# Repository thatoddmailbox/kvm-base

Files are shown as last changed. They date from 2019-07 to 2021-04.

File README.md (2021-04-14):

# kvm-base


The main board for the [open-source HDMI KVM switch I built](https://github.com/thatoddmailbox/kvm#kvm). Contains HDMI and USB switch ICs, allowing you to share two monitors and four USB devices between three different computers.

This is a 1.6mm four layer PCB, designed for JLCPCB's [JLC7628](https://jlcpcb.com/quote/pcbOrderFaq/PCB%20Stackup) impedance-controlled stackup. It most likely will not work (or will be limited in terms of HDMI performance) on another stackup.

It connects via a PS/2 cable to [kvm-keypad](https://github.com/thatoddmailbox/kvm-keypad)&mdash;however, it does _not_ use the actual PS/2 protocol.

Two [TMDS361B](https://www.ti.com/lit/ds/symlink/tmds361b.pdf) chips are used as HDMI switches, and an [FSUSB74](https://www.onsemi.com/pub/Collateral/FSUSB74-D.pdf) is used as the USB switch.

## Assembly
The full Bill of Materials is linked at the end of the README, and you should get the PCB fabricated at JLCPCB with their impedance-controlled JLC7628 process.

A stencil is probably the easiest way to assemble the board, but it's definitely possible to do so without one, as long as you have a hot air rework station. The trickiest parts to solder are probably the FSUSB74 (QFN with 0.4 mm pitch but no thermal pad) and the TMDS361B (TQFP with 0.5 mm pitch).

The HDMI connectors are also somewhat tricky, given that they are on both sides of the board and also have a relatively fine pitch. However, it's doable with a soldering iron, flux, solder wick, and ideally some form of magnification&mdash;you just have to be careful to ensure the pins are aligned with the footprint on the board before soldering.

## Note on sink-side output stages
Interestingly, the TMDS361B's datasheet pretty clearly states that it's "not intended for source side applications such as external switch boxes", which I probably missed when designing this board.

The consequences of this seem to be that there's little/no ESD protection on the sink side (the monitor output ports), and that the chip has a fairly weak sink-side output stage. That means you probably can't use the output with super long or super cheap cables. The inputs, however, should be fine, since TI claims that the TMDS361B has a "robust TMDS receive stage" that even works with out-of-spec HDMI signals.

Anecdotally, the output does seem to work, but I haven't tested it in that many conditions. This has been tested with a 3 foot HDMI cable going to an Acer EB243YU monitor, using a resolution of 2560 x 1440 at 75 Hz, which is outside of the TMDS361B's spec!

Theoretically, you might be able to work around this by running the output signals to another board with a retimer or redriver, but that's probably somewhat excessive. A future revision should use a different chip and/or integrate a retimer/redriver to the output stage. Unfortunately, it might be somewhat tricky to find an easily accessible HDMI switch chip&mdash;most seem to want you to sign an NDA before getting any documentation.

## Useful links
* [Rev A schematic](./mfg/revA/kvm-base.pdf)
* [Rev A BOM](./mfg/revA/kvm-base.csv)

## Known issues
* TMDS361B's sink-side output stages, as mentioned above
* HDMI ports are too close together -- some cables might be too big to fit
* Some FSUSB74 ports seem to not be working -- this could be a soldering issue
	* Port 2 works perfectly
	* With ports 0 and 1, the computer detects a device but then complains the device is not responding
	* Suspect that probably one of the D+/D- lines is not well connected
* The HPD and DDC lines are switched along with the ports. This means that switching ports will cause the connected source to think the monitor went away, which might not be what you want
	* A future version will probably need to have some sort of EDID cloning/emulation, or have some way to keep the HPD line high after the monitor is connected?
	* There is a workaround: cover the HPD pin (pin 19) of your HDMI cable with tape to block the HPD signal.
		* This workaround means that some sources, like a laptop, might not autodetect your HDMI cable. You'll need to have some way to rescan. On Linux, you can try the command `xrandr --listmonitors`.
		* This might be solvable by cutting the cable open and soldering a 10k resistor between HPD and +5V? That's somewhat extra though
* The device can kinda sorta be powered by a sink&mdash;most likely the ESD diodes in the TMDS361B are backfeeding power on the +5V line.
* The keypad might have some trouble with noise when a PS/2 cable is connected, although it has been worked around in the firmware. A future revision might need a buffer or redriver or something similar? Plain I2C is probably not the best choice for communication between the base and keypad.

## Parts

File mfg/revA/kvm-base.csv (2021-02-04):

Reference | Value | Footprint | Datasheet
U3 | STM8S003F3P | Package_SO:TSSOP-20_4.4x6.5mm_P0.65mm | http://www.st.com/st-web-ui/static/active/en/resource/technical/document/datasheet/DM00024550.pdf
U2 | FSUSB74 | kvm-base:UMLP16 | https://www.onsemi.com/pub/Collateral/FSUSB74-D.pdf
J1 | USB_B_Mini | Connector_USB:USB_Mini-B_Lumberg_2486_01_Horizontal | ~
J2 | USB_B_Mini | Connector_USB:USB_Mini-B_Lumberg_2486_01_Horizontal | ~
J3 | USB_B_Mini | Connector_USB:USB_Mini-B_Lumberg_2486_01_Horizontal | ~
J4 | USB_B_Mini | Connector_USB:USB_Mini-B_Lumberg_2486_01_Horizontal | ~
U1 | AMS1117-3.3 | Package_TO_SOT_SMD:SOT-223-3_TabPin2 | http://www.advanced-monolithic.com/pdf/ds1117.pdf
C1 | 10uF | Capacitor_SMD:C_0603_1608Metric_Pad1.05x0.95mm_HandSolder | ~
C2 | 10uF | Capacitor_SMD:C_0603_1608Metric_Pad1.05x0.95mm_HandSolder | ~
C3 | 0.1uF | Capacitor_SMD:C_0603_1608Metric_Pad1.05x0.95mm_HandSolder | ~
C5 | 0.1uF | Capacitor_SMD:C_0603_1608Metric_Pad1.05x0.95mm_HandSolder | ~
C4 | 0.47uF | Capacitor_SMD:C_0603_1608Metric_Pad1.05x0.95mm_HandSolder | ~
J6 | Debug | Connector_PinSocket_2.54mm:PinSocket_2x04_P2.54mm_Vertical | ~
SW1 | Reset | Button_Switch_SMD:SW_Push_1P1T_NO_6x6mm_H9.5mm | ~
J5 | Keypad | kvm-base:PS2 | http://service.powerdynamics.com/ec/Catalog17/Section%2011.pdf
R7 | 10k | Resistor_SMD:R_0603_1608Metric_Pad1.05x0.95mm_HandSolder | ~
R5 | 10k | Resistor_SMD:R_0603_1608Metric_Pad1.05x0.95mm_HandSolder | ~
R8 | 10k | Resistor_SMD:R_0603_1608Metric_Pad1.05x0.95mm_HandSolder | ~
R6 | 10k | Resistor_SMD:R_0603_1608Metric_Pad1.05x0.95mm_HandSolder | ~
J7 | HDMI_A | kvm-base:HDMI-001 | https://en.wikipedia.org/wiki/HDMI
J10 | HDMI_A | kvm-base:HDMI-001 | https://en.wikipedia.org/wiki/HDMI
U4 | TMDS361B | Package_QFP:LQFP-64_10x10mm_P0.5mm | https://www.ti.com/lit/ds/symlink/tmds361b.pdf
J9 | HDMI_A | kvm-base:HDMI-001 | https://en.wikipedia.org/wiki/HDMI
J8 | HDMI_A | kvm-base:HDMI-001 | https://en.wikipedia.org/wiki/HDMI
C6 | 1uF | Capacitor_SMD:C_0603_1608Metric_Pad1.05x0.95mm_HandSolder | ~
C7 | 1uF | Capacitor_SMD:C_0603_1608Metric_Pad1.05x0.95mm_HandSolder | ~
C8 | 0.1uF | Capacitor_SMD:C_0603_1608Metric_Pad1.05x0.95mm_HandSolder | ~
C9 | 0.1uF | Capacitor_SMD:C_0603_1608Metric_Pad1.05x0.95mm_HandSolder | ~
C10 | 1uF | Capacitor_SMD:C_0603_1608Metric_Pad1.05x0.95mm_HandSolder | ~
C11 | 1uF | Capacitor_SMD:C_0603_1608Metric_Pad1.05x0.95mm_HandSolder | ~
C12 | 0.1uF | Capacitor_SMD:C_0603_1608Metric_Pad1.05x0.95mm_HandSolder | ~
C13 | 0.1uF | Capacitor_SMD:C_0603_1608Metric_Pad1.05x0.95mm_HandSolder | ~
R2 | 4.02k | Resistor_SMD:R_0603_1608Metric_Pad1.05x0.95mm_HandSolder | ~
R1 | 10k | Resistor_SMD:R_0603_1608Metric_Pad1.05x0.95mm_HandSolder | ~
R9 | 5.9k | Resistor_SMD:R_0603_1608Metric_Pad1.05x0.95mm_HandSolder | ~
R10 | 5.9k | Resistor_SMD:R_0603_1608Metric_Pad1.05x0.95mm_HandSolder | ~
J11 | HDMI_A | kvm-base:HDMI-001 | https://en.wikipedia.org/wiki/HDMI
U5 | TMDS361B | Package_QFP:LQFP-64_10x10mm_P0.5mm | https://www.ti.com/lit/ds/symlink/tmds361b.pdf
J13 | HDMI_A | kvm-base:HDMI-001 | https://en.wikipedia.org/wiki/HDMI
J12 | HDMI_A | kvm-base:HDMI-001 | https://en.wikipedia.org/wiki/HDMI
C14 | 1uF | Capacitor_SMD:C_0603_1608Metric_Pad1.05x0.95mm_HandSolder | ~
C15 | 1uF | Capacitor_SMD:C_0603_1608Metric_Pad1.05x0.95mm_HandSolder | ~
C16 | 0.1uF | Capacitor_SMD:C_0603_1608Metric_Pad1.05x0.95mm_HandSolder | ~
C17 | 0.1uF | Capacitor_SMD:C_0603_1608Metric_Pad1.05x0.95mm_HandSolder | ~
C18 | 1uF | Capacitor_SMD:C_0603_1608Metric_Pad1.05x0.95mm_HandSolder | ~
C19 | 1uF | Capacitor_SMD:C_0603_1608Metric_Pad1.05x0.95mm_HandSolder | ~
C20 | 0.1uF | Capacitor_SMD:C_0603_1608Metric_Pad1.05x0.95mm_HandSolder | ~
C21 | 0.1uF | Capacitor_SMD:C_0603_1608Metric_Pad1.05x0.95mm_HandSolder | ~
R4 | 4.02k | Resistor_SMD:R_0603_1608Metric_Pad1.05x0.95mm_HandSolder | ~
R3 | 10k | Resistor_SMD:R_0603_1608Metric_Pad1.05x0.95mm_HandSolder | ~
J14 | HDMI_A | kvm-base:HDMI-001 | https://en.wikipedia.org/wiki/HDMI
R11 | 5.9k | Resistor_SMD:R_0603_1608Metric_Pad1.05x0.95mm_HandSolder | ~
R12 | 5.9k | Resistor_SMD:R_0603_1608Metric_Pad1.05x0.95mm_HandSolder | ~
U6 | SL2.1A | Package_SO:SOIC-16_3.9x9.9mm_P1.27mm
C24 | 10uF | Capacitor_SMD:C_0603_1608Metric_Pad1.05x0.95mm_HandSolder | ~
J15 | USB_Dual_A | Connector_USB:USB_A_Wuerth_61400826021_Horizontal_Stacked | ~
J16 | USB_Dual_A | Connector_USB:USB_A_Wuerth_61400826021_Horizontal_Stacked | ~
C25 | 10uF | Capacitor_SMD:C_0603_1608Metric_Pad1.05x0.95mm_HandSolder | ~
Y1 | 12MHz | Crystal:Crystal_SMD_3225-4Pin_3.2x2.5mm_HandSoldering | ~
C23 | 12pF | Capacitor_SMD:C_0603_1608Metric_Pad1.05x0.95mm_HandSolder | ~
C22 | 12pF | Capacitor_SMD:C_0603_1608Metric_Pad1.05x0.95mm_HandSolder | ~
C29 | 10uF | Capacitor_SMD:C_0603_1608Metric_Pad1.05x0.95mm_HandSolder | ~
C26 | 10uF | Capacitor_SMD:C_0603_1608Metric_Pad1.05x0.95mm_HandSolder | ~
C28 | 10uF | Capacitor_SMD:C_0603_1608Metric_Pad1.05x0.95mm_HandSolder | ~
C27 | 10uF | Capacitor_SMD:C_0603_1608Metric_Pad1.05x0.95mm_HandSolder | ~

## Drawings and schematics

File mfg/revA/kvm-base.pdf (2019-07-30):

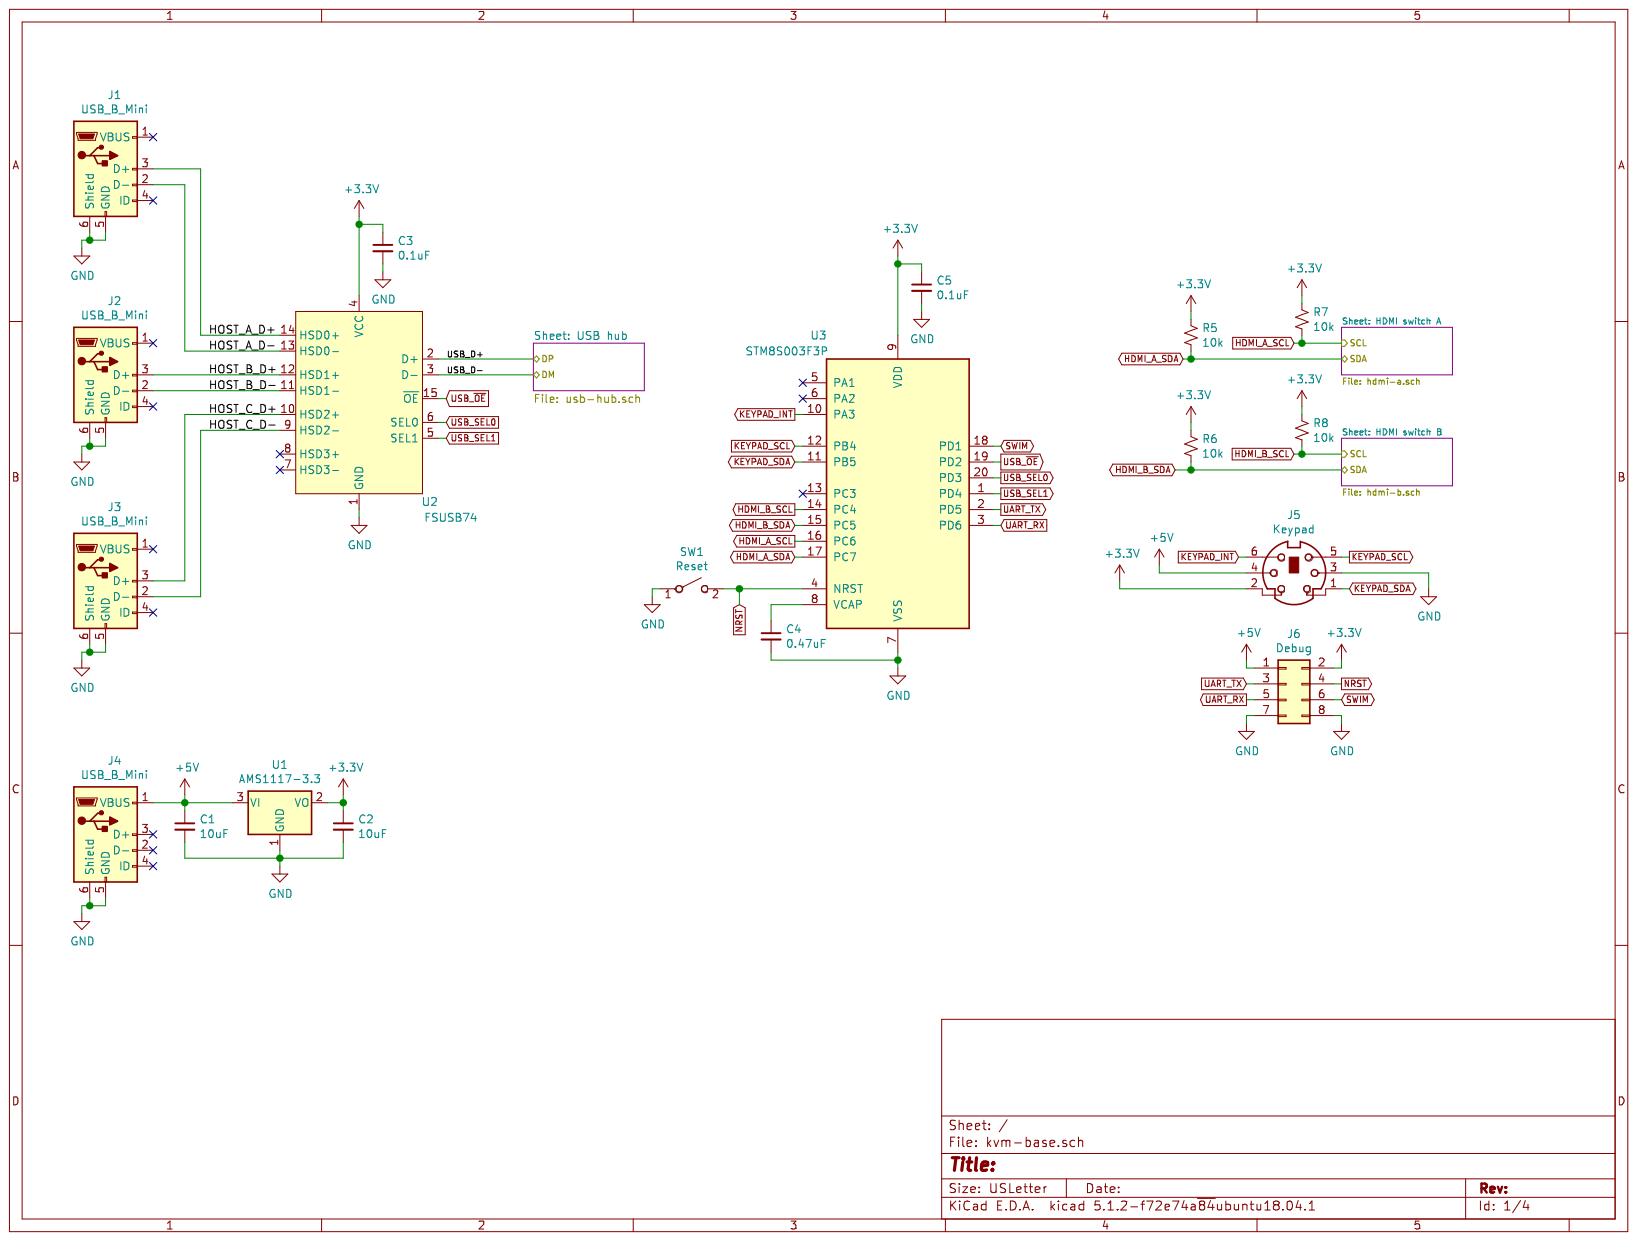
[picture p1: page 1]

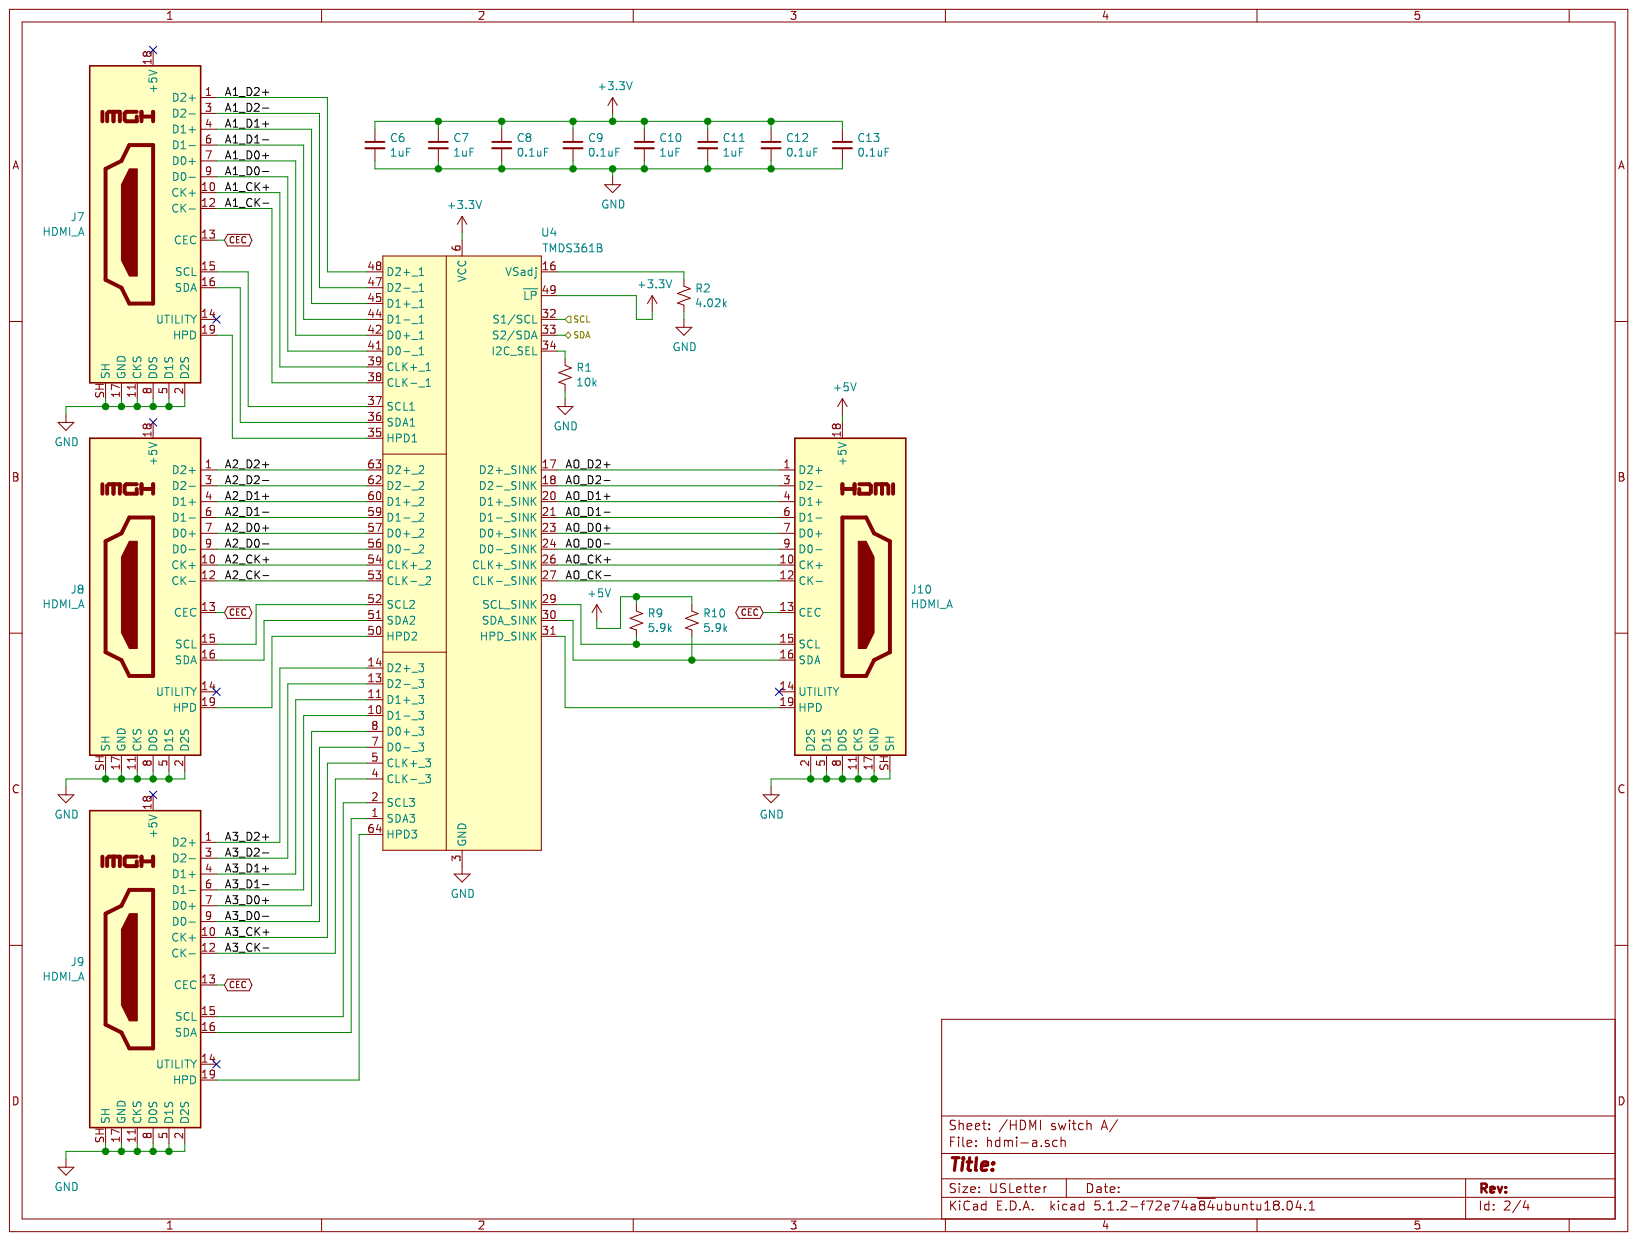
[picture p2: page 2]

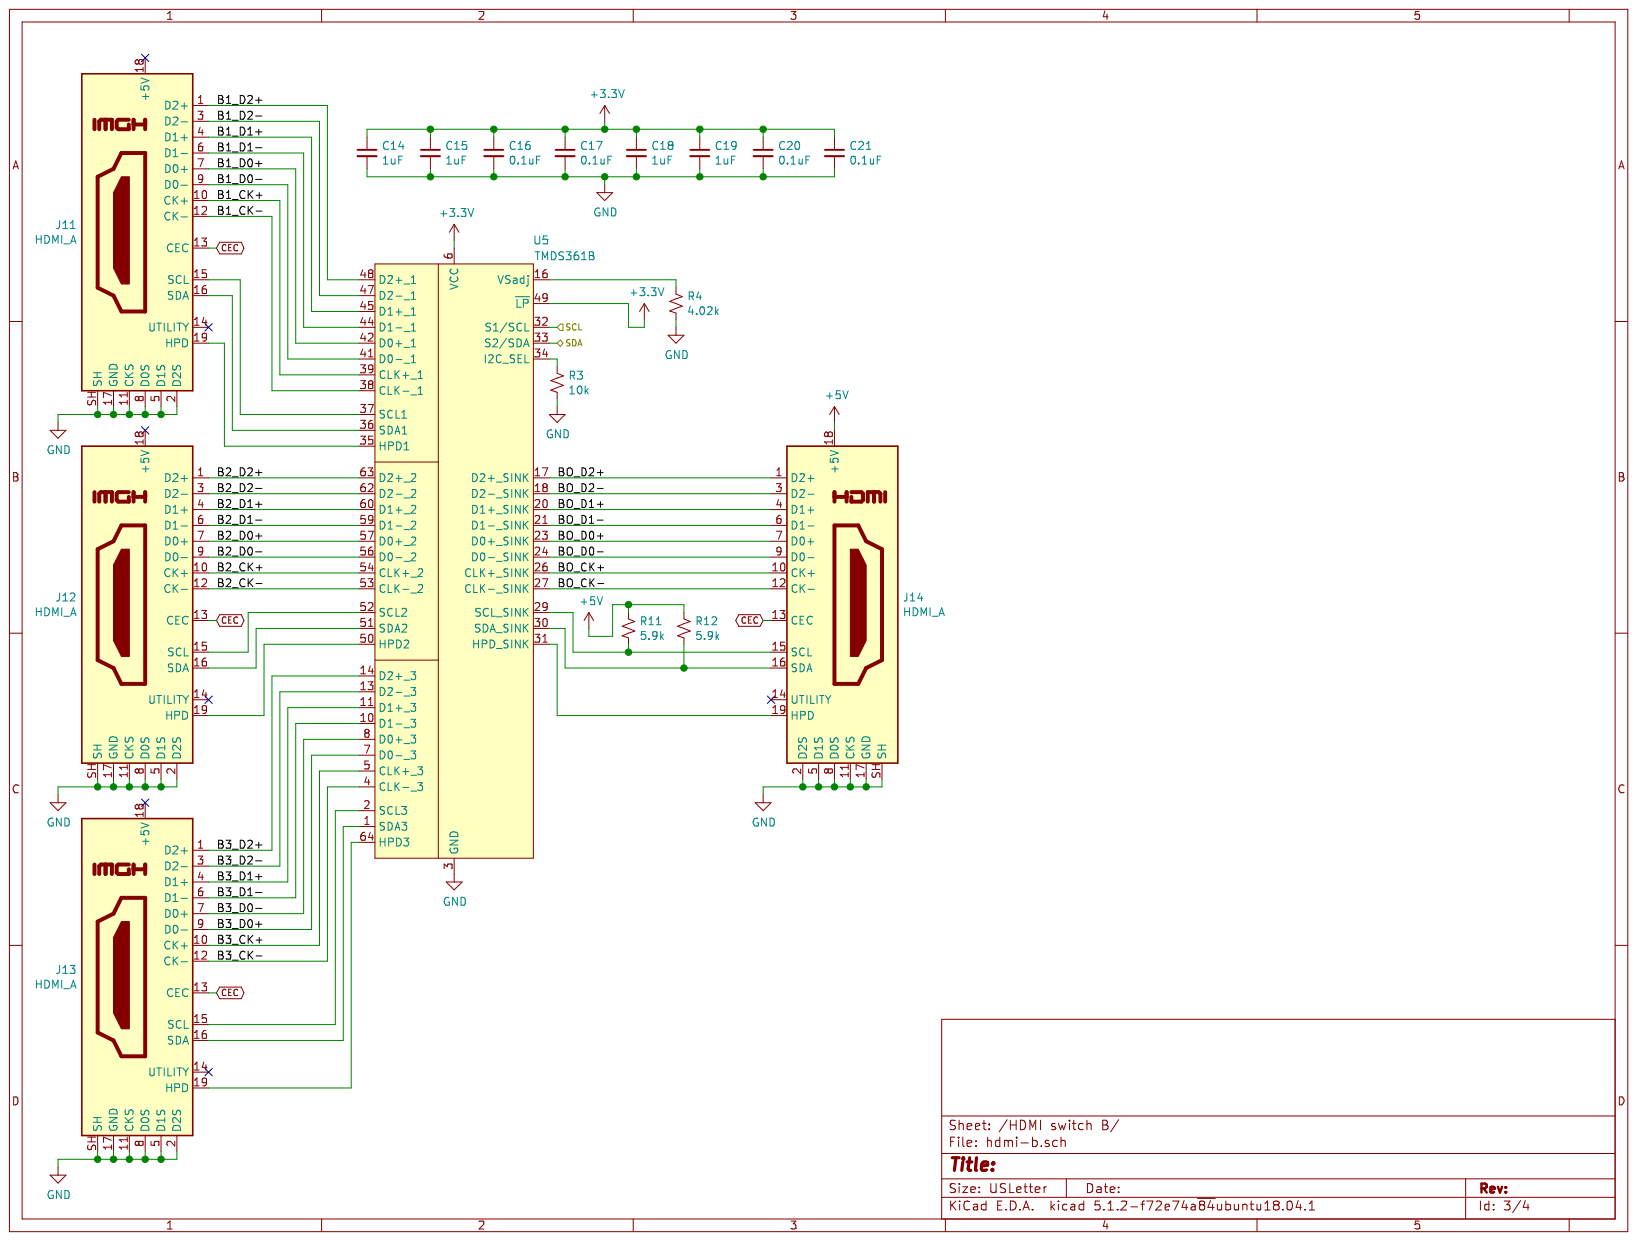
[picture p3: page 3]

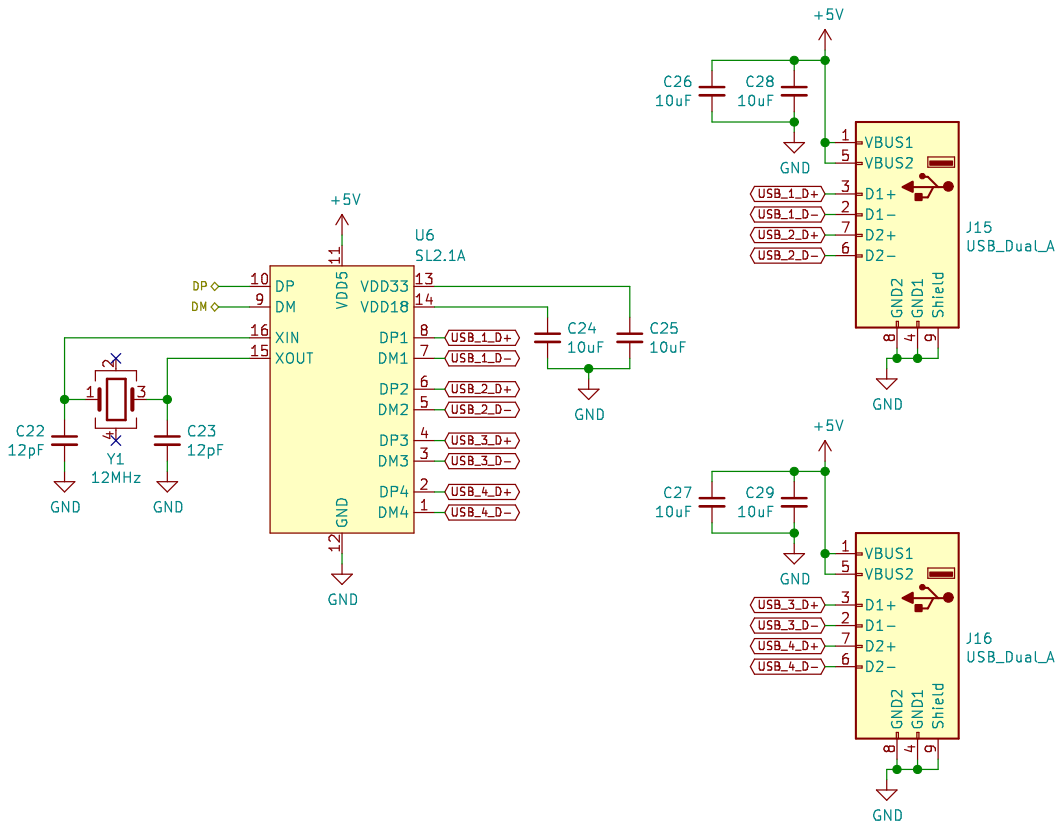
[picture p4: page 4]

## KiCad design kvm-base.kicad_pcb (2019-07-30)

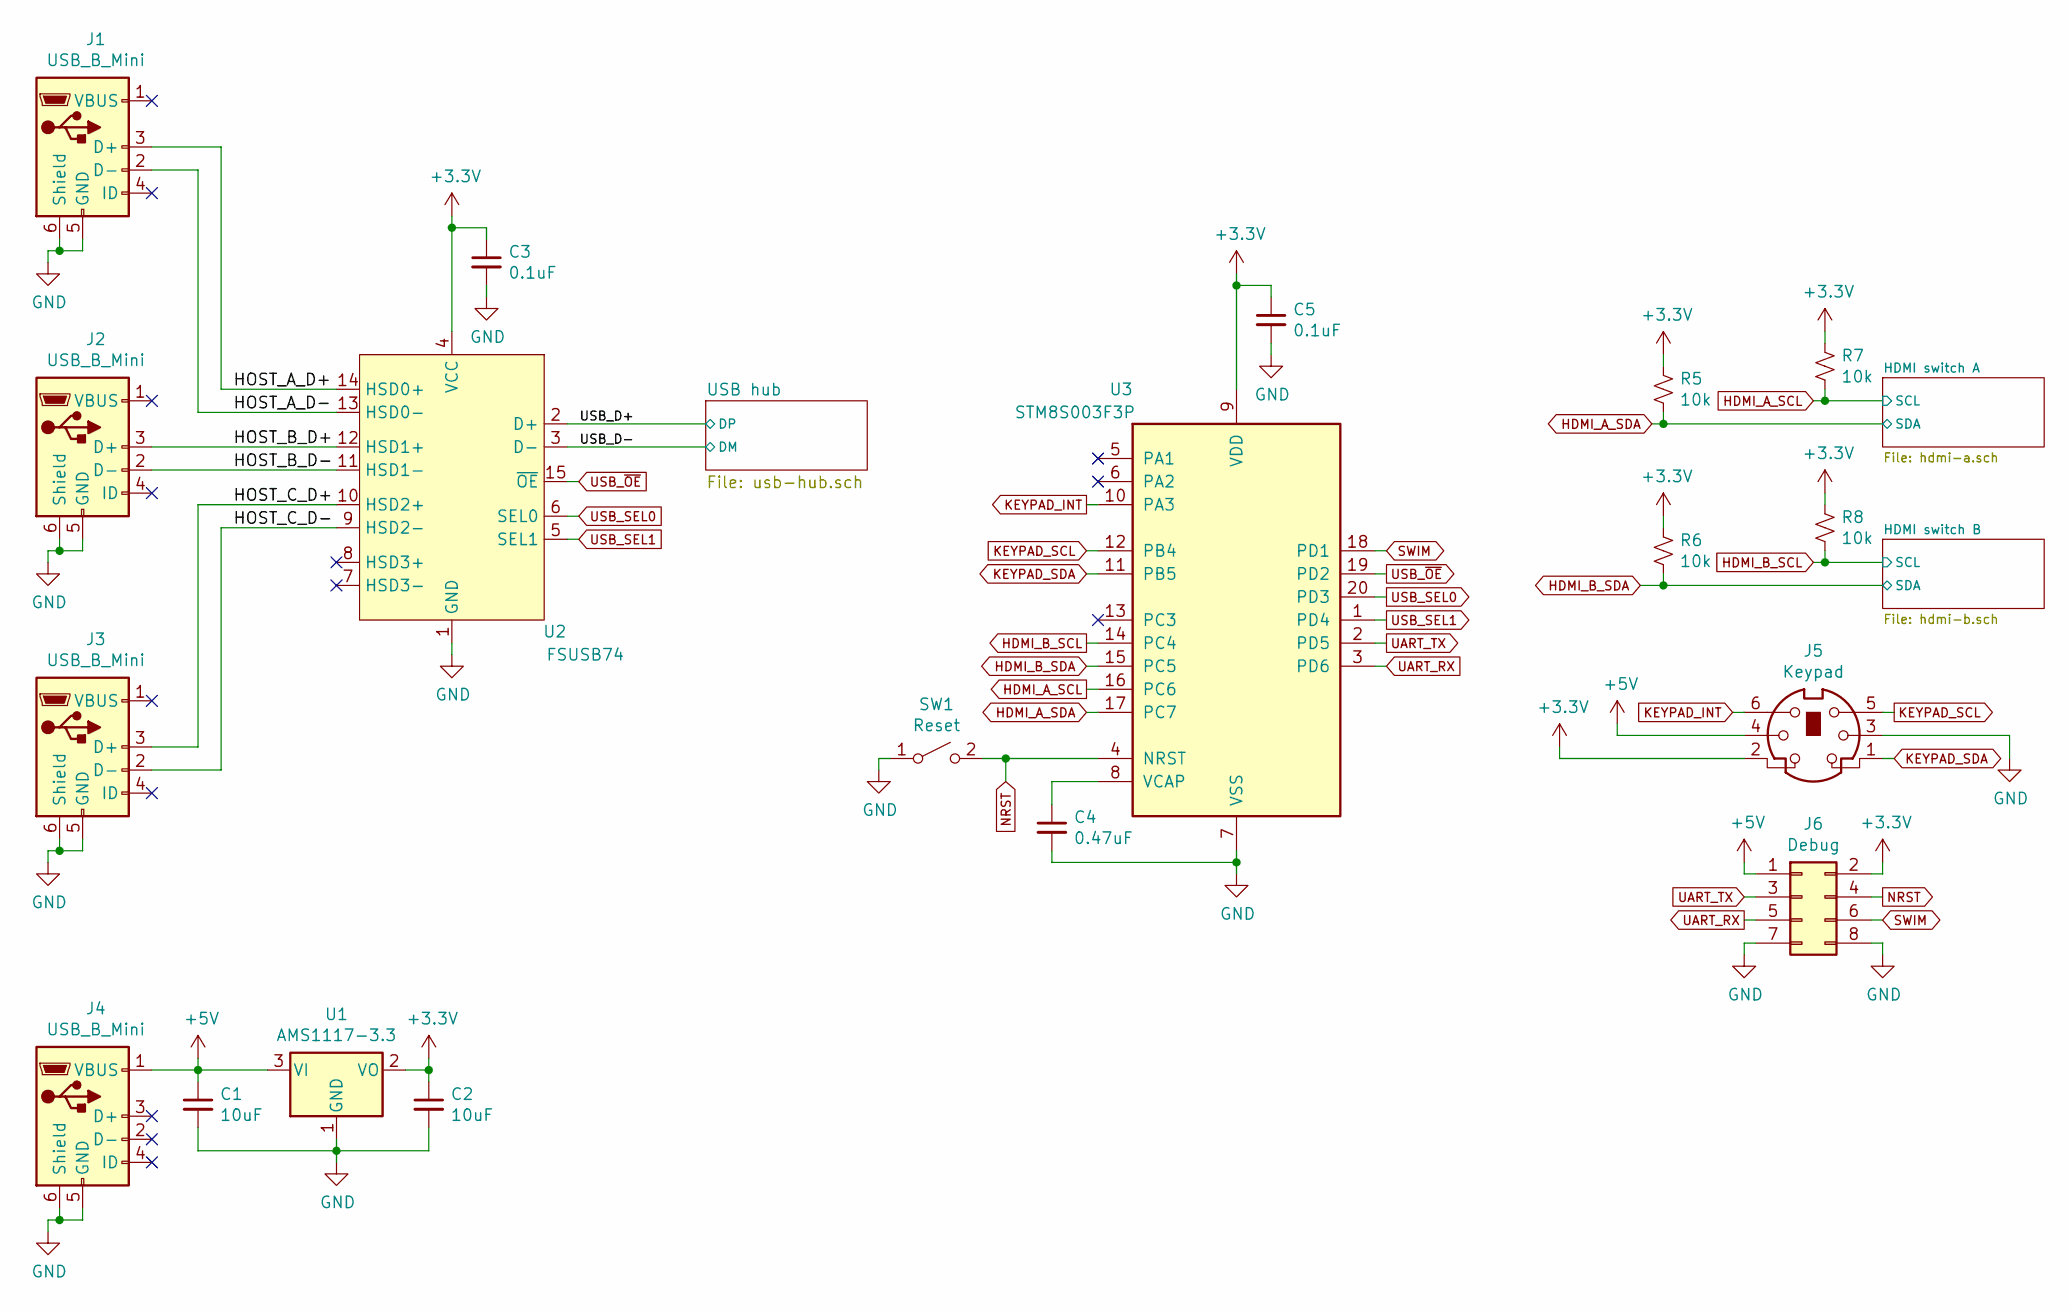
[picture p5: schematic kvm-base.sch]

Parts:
C1, C2: 10uF; C_0603_1608Metric_Pad1.05x0.95mm_HandSolder
C3, C5: 0.1uF; C_0603_1608Metric_Pad1.05x0.95mm_HandSolder
C4: 0.47uF; C_0603_1608Metric_Pad1.05x0.95mm_HandSolder
J1, J2, J3, J4: USB_B_Mini; USB_Mini-B_Lumberg_2486_01_Horizontal
J5: Keypad; PS2
J6: Debug; PinSocket_2x04_P2.54mm_Vertical
R5, R6, R7, R8: 10k; R_0603_1608Metric_Pad1.05x0.95mm_HandSolder
SW1: Reset; SW_Push_1P1T_NO_6x6mm_H9.5mm
U1: AMS1117-3.3; SOT-223-3_TabPin2
U2: FSUSB74; UMLP16
U3: STM8S003F3P; TSSOP-20_4.4x6.5mm_P0.65mm

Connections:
+3V3: C2.1, C3.1, C5.1, J5.2, J6.2, R5.1, R6.1, R7.1, R8.1, U1.2 (VO), U2.4 (VCC), U3.9 (VDD); also elsewhere on the board
+5V: C1.1, J4.1 (VBUS), J5.4, J6.1, U1.3 (VI); also elsewhere on the board
/HOST_A_D+: J1.3 (D+), U2.14 (HSD0+)
/HOST_A_D-: J1.2 (D-), U2.13 (HSD0-)
/HOST_B_D+: J2.3 (D+), U2.12 (HSD1+)
/HOST_B_D-: J2.2 (D-), U2.11 (HSD1-)
/HOST_C_D+: J3.3 (D+), U2.10 (HSD2+)
/HOST_C_D-: J3.2 (D-), U2.9 (HSD2-)
/USB_D+: U2.2 (D+); also elsewhere on the board
/USB_D-: U2.3 (D-); also elsewhere on the board
GND: C1.2, C2.2, C3.2, C4.2, C5.2, J1.5 (GND), J1.6 (Shield), J2.5 (GND), J2.6 (Shield), J3.5 (GND), J3.6 (Shield), J4.5 (GND), J4.6 (Shield), J5.3, J6.7, J6.8, SW1.1 (A), U1.1 (GND), U2.1 (GND), U3.7 (VSS); also elsewhere on the board
HDMI_A_SCL: R7.2, U3.16 (PC6); also elsewhere on the board
HDMI_A_SDA: R5.2, U3.17 (PC7); also elsewhere on the board
HDMI_B_SCL: R8.2, U3.14 (PC4); also elsewhere on the board
HDMI_B_SDA: R6.2, U3.15 (PC5); also elsewhere on the board
KEYPAD_INT: J5.6, U3.10 (PA3)
KEYPAD_SCL: J5.5, U3.12 (PB4)
KEYPAD_SDA: J5.1, U3.11 (PB5)
NRST: J6.4, SW1.2 (B), U3.4 (NRST)
unnamed: C4.1, U3.8 (VCAP)
SWIM: J6.6, U3.18 (PD1)
UART_RX: J6.5, U3.3 (PD6)
UART_TX: J6.3, U3.2 (PD5)
USB_SEL0: U2.6 (SEL0), U3.20 (PD3)
USB_SEL1: U2.5 (SEL1), U3.1 (PD4)
USB_~OE: U2.15 (~OE), U3.19 (PD2)

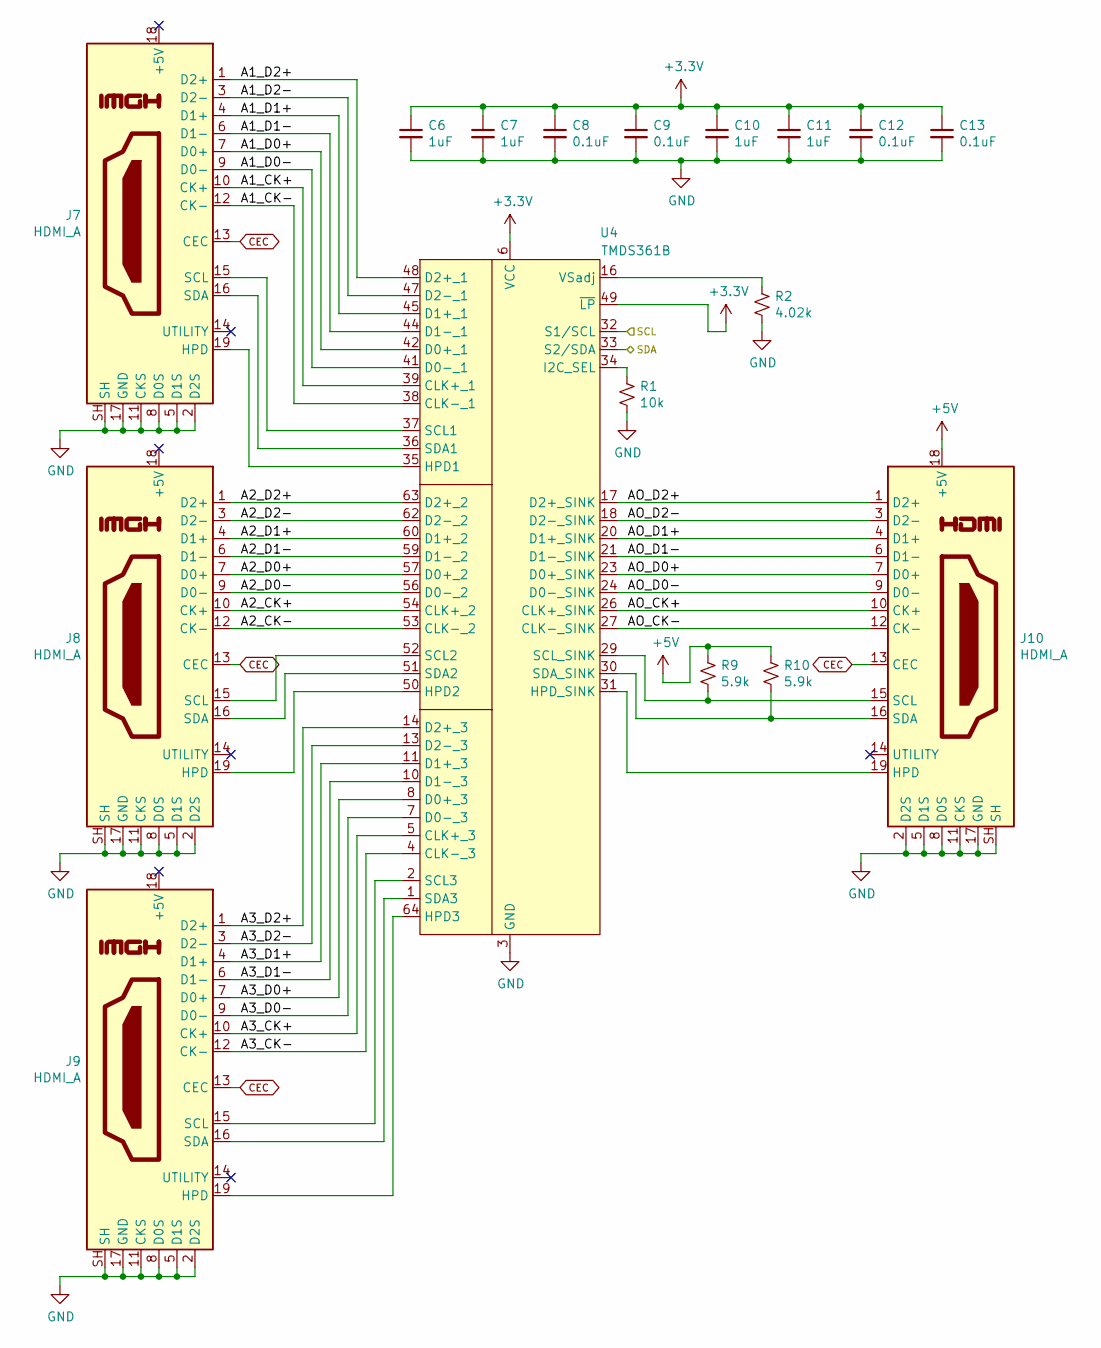
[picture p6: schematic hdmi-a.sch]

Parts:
C6, C7, C10, C11: 1uF; C_0603_1608Metric_Pad1.05x0.95mm_HandSolder
C8, C9, C12, C13: 0.1uF; C_0603_1608Metric_Pad1.05x0.95mm_HandSolder
J7, J8, J9, J10: HDMI_A; HDMI-001
R1: 10k; R_0603_1608Metric_Pad1.05x0.95mm_HandSolder
R2: 4.02k; R_0603_1608Metric_Pad1.05x0.95mm_HandSolder
R9, R10: 5.9k; R_0603_1608Metric_Pad1.05x0.95mm_HandSolder
U4: TMDS361B; LQFP-64_10x10mm_P0.5mm

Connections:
+3V3: C6.1, C7.1, C8.1, C9.1, C10.1, C11.1, C12.1, C13.1, U4.6 (VCC), U4.12 (VCC), U4.19 (VCC), U4.25 (VCC), U4.40 (VCC), U4.46 (VCC), U4.49 (~LP), U4.55 (VCC), U4.61 (VCC); also elsewhere on the board
+5V: J10.18 (+5V), R9.1, R10.1; also elsewhere on the board
/HDMI switch A/A1_CK+: J7.10 (CK+), U4.39 (CLK+_1)
/HDMI switch A/A1_CK-: J7.12 (CK-), U4.38 (CLK-_1)
/HDMI switch A/A1_D0+: J7.7 (D0+), U4.42 (D0+_1)
/HDMI switch A/A1_D0-: J7.9 (D0-), U4.41 (D0-_1)
/HDMI switch A/A1_D1+: J7.4 (D1+), U4.45 (D1+_1)
/HDMI switch A/A1_D1-: J7.6 (D1-), U4.44 (D1-_1)
/HDMI switch A/A1_D2+: J7.1 (D2+), U4.48 (D2+_1)
/HDMI switch A/A1_D2-: J7.3 (D2-), U4.47 (D2-_1)
/HDMI switch A/A2_CK+: J8.10 (CK+), U4.54 (CLK+_2)
/HDMI switch A/A2_CK-: J8.12 (CK-), U4.53 (CLK-_2)
/HDMI switch A/A2_D0+: J8.7 (D0+), U4.57 (D0+_2)
/HDMI switch A/A2_D0-: J8.9 (D0-), U4.56 (D0-_2)
/HDMI switch A/A2_D1+: J8.4 (D1+), U4.60 (D1+_2)
/HDMI switch A/A2_D1-: J8.6 (D1-), U4.59 (D1-_2)
/HDMI switch A/A2_D2+: J8.1 (D2+), U4.63 (D2+_2)
/HDMI switch A/A2_D2-: J8.3 (D2-), U4.62 (D2-_2)
/HDMI switch A/A3_CK+: J9.10 (CK+), U4.5 (CLK+_3)
/HDMI switch A/A3_CK-: J9.12 (CK-), U4.4 (CLK-_3)
/HDMI switch A/A3_D0+: J9.7 (D0+), U4.8 (D0+_3)
/HDMI switch A/A3_D0-: J9.9 (D0-), U4.7 (D0-_3)
/HDMI switch A/A3_D1+: J9.4 (D1+), U4.11 (D1+_3)
/HDMI switch A/A3_D1-: J9.6 (D1-), U4.10 (D1-_3)
/HDMI switch A/A3_D2+: J9.1 (D2+), U4.14 (D2+_3)
/HDMI switch A/A3_D2-: J9.3 (D2-), U4.13 (D2-_3)
/HDMI switch A/AO_CK+: J10.10 (CK+), U4.26 (CLK+_SINK)
/HDMI switch A/AO_CK-: J10.12 (CK-), U4.27 (CLK-_SINK)
/HDMI switch A/AO_D0+: J10.7 (D0+), U4.23 (D0+_SINK)
/HDMI switch A/AO_D0-: J10.9 (D0-), U4.24 (D0-_SINK)
/HDMI switch A/AO_D1+: J10.4 (D1+), U4.20 (D1+_SINK)
/HDMI switch A/AO_D1-: J10.6 (D1-), U4.21 (D1-_SINK)
/HDMI switch A/AO_D2+: J10.1 (D2+), U4.17 (D2+_SINK)
/HDMI switch A/AO_D2-: J10.3 (D2-), U4.18 (D2-_SINK)
CEC: J7.13 (CEC), J8.13 (CEC), J9.13 (CEC), J10.13 (CEC); also elsewhere on the board
GND: C6.2, C7.2, C8.2, C9.2, C10.2, C11.2, C12.2, C13.2, J7.2 (D2S), J7.5 (D1S), J7.8 (D0S), J7.11 (CKS), J7.17 (GND), J7.SH, J8.2 (D2S), J8.5 (D1S), J8.8 (D0S), J8.11 (CKS), J8.17 (GND), J8.SH, J9.2 (D2S), J9.5 (D1S), J9.8 (D0S), J9.11 (CKS), J9.17 (GND), J9.SH, J10.2 (D2S), J10.5 (D1S), J10.8 (D0S), J10.11 (CKS), J10.17 (GND), J10.SH, R1.2, R2.2, U4.3 (GND), U4.9 (GND), U4.15 (GND), U4.22 (GND), U4.28 (GND), U4.43 (GND), U4.58 (GND); also elsewhere on the board
HDMI_A_SCL: U4.32 (S1/SCL); also elsewhere on the board
HDMI_A_SDA: U4.33 (S2/SDA); also elsewhere on the board
unnamed: J7.15 (SCL), U4.37 (SCL1)
unnamed: J7.16 (SDA), U4.36 (SDA1)
unnamed: J7.19 (HPD), U4.35 (HPD1)
unnamed: J8.15 (SCL), U4.52 (SCL2)
unnamed: J8.16 (SDA), U4.51 (SDA2)
unnamed: J8.19 (HPD), U4.50 (HPD2)
unnamed: J9.15 (SCL), U4.2 (SCL3)
unnamed: J9.16 (SDA), U4.1 (SDA3)
unnamed: J9.19 (HPD), U4.64 (HPD3)
unnamed: J10.15 (SCL), R9.2, U4.29 (SCL_SINK)
unnamed: J10.16 (SDA), R10.2, U4.30 (SDA_SINK)
unnamed: J10.19 (HPD), U4.31 (HPD_SINK)
unnamed: R1.1, U4.34 (I2C_SEL)
unnamed: R2.1, U4.16 (VSadj)

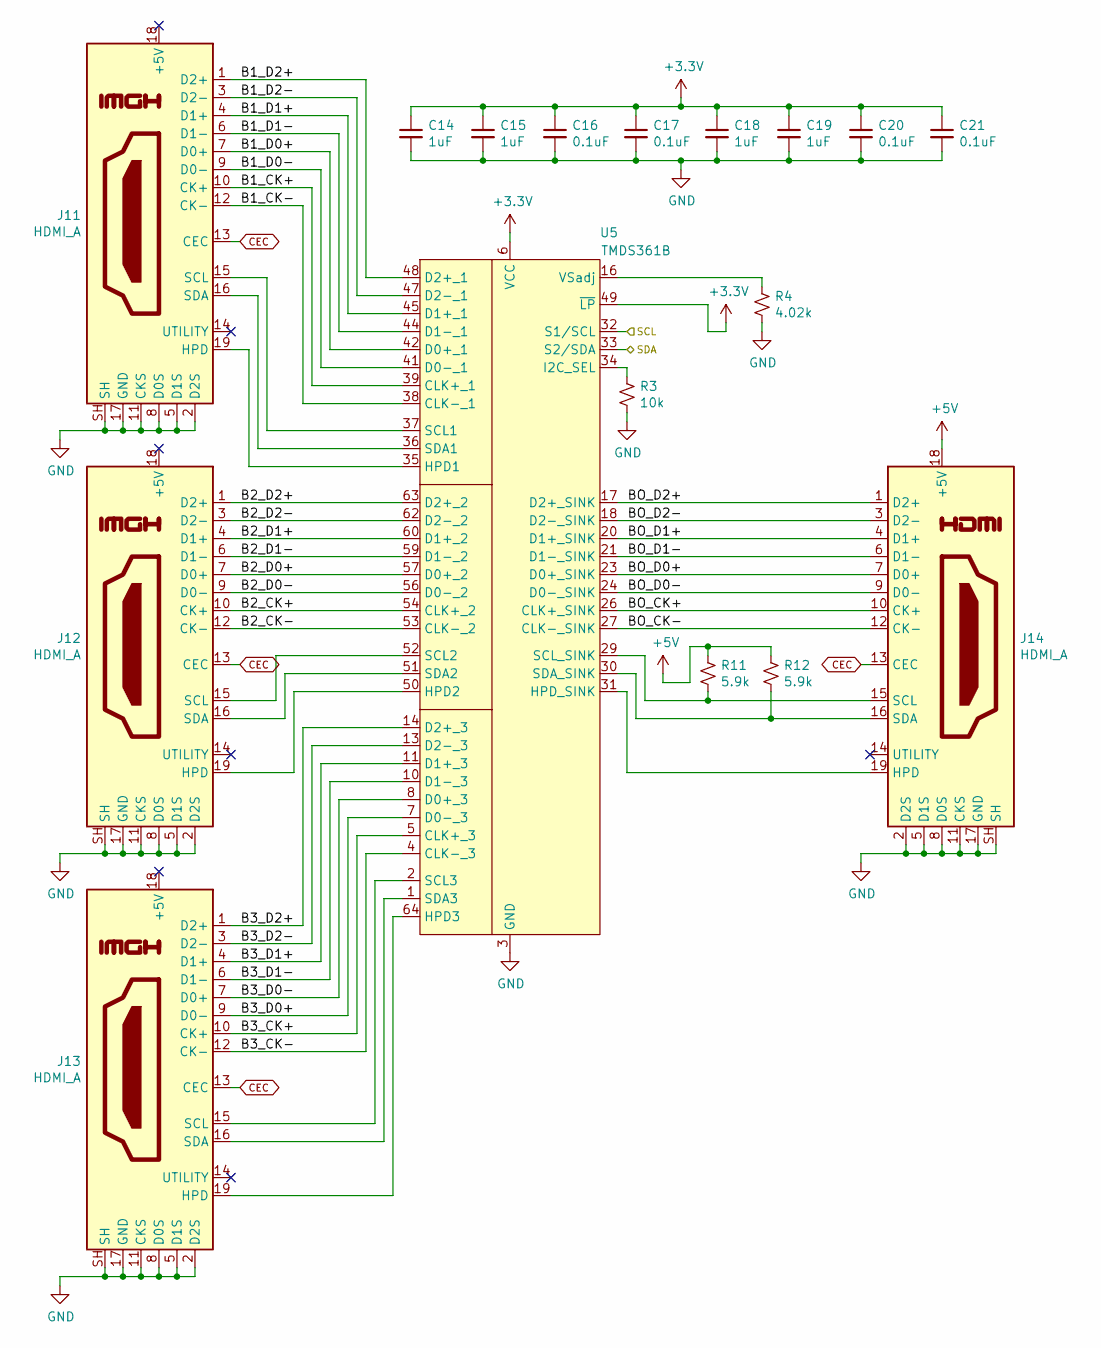
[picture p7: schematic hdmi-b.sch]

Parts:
C14, C15, C18, C19: 1uF; C_0603_1608Metric_Pad1.05x0.95mm_HandSolder
C16, C17, C20, C21: 0.1uF; C_0603_1608Metric_Pad1.05x0.95mm_HandSolder
J11, J12, J13, J14: HDMI_A; HDMI-001
R3: 10k; R_0603_1608Metric_Pad1.05x0.95mm_HandSolder
R4: 4.02k; R_0603_1608Metric_Pad1.05x0.95mm_HandSolder
R11, R12: 5.9k; R_0603_1608Metric_Pad1.05x0.95mm_HandSolder
U5: TMDS361B; LQFP-64_10x10mm_P0.5mm

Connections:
+3V3: C14.1, C15.1, C16.1, C17.1, C18.1, C19.1, C20.1, C21.1, U5.6 (VCC), U5.12 (VCC), U5.19 (VCC), U5.25 (VCC), U5.40 (VCC), U5.46 (VCC), U5.49 (~LP), U5.55 (VCC), U5.61 (VCC); also elsewhere on the board
+5V: J14.18 (+5V), R11.1, R12.1; also elsewhere on the board
/HDMI switch B/B1_CK+: J11.10 (CK+), U5.39 (CLK+_1)
/HDMI switch B/B1_CK-: J11.12 (CK-), U5.38 (CLK-_1)
/HDMI switch B/B1_D0+: J11.7 (D0+), U5.42 (D0+_1)
/HDMI switch B/B1_D0-: J11.9 (D0-), U5.41 (D0-_1)
/HDMI switch B/B1_D1+: J11.4 (D1+), U5.45 (D1+_1)
/HDMI switch B/B1_D1-: J11.6 (D1-), U5.44 (D1-_1)
/HDMI switch B/B1_D2+: J11.1 (D2+), U5.48 (D2+_1)
/HDMI switch B/B1_D2-: J11.3 (D2-), U5.47 (D2-_1)
/HDMI switch B/B2_CK+: J12.10 (CK+), U5.54 (CLK+_2)
/HDMI switch B/B2_CK-: J12.12 (CK-), U5.53 (CLK-_2)
/HDMI switch B/B2_D0+: J12.7 (D0+), U5.57 (D0+_2)
/HDMI switch B/B2_D0-: J12.9 (D0-), U5.56 (D0-_2)
/HDMI switch B/B2_D1+: J12.4 (D1+), U5.60 (D1+_2)
/HDMI switch B/B2_D1-: J12.6 (D1-), U5.59 (D1-_2)
/HDMI switch B/B2_D2+: J12.1 (D2+), U5.63 (D2+_2)
/HDMI switch B/B2_D2-: J12.3 (D2-), U5.62 (D2-_2)
/HDMI switch B/B3_CK+: J13.10 (CK+), U5.5 (CLK+_3)
/HDMI switch B/B3_CK-: J13.12 (CK-), U5.4 (CLK-_3)
/HDMI switch B/B3_D0+: J13.9 (D0-), U5.7 (D0-_3)
/HDMI switch B/B3_D0-: J13.7 (D0+), U5.8 (D0+_3)
/HDMI switch B/B3_D1+: J13.4 (D1+), U5.11 (D1+_3)
/HDMI switch B/B3_D1-: J13.6 (D1-), U5.10 (D1-_3)
/HDMI switch B/B3_D2+: J13.1 (D2+), U5.14 (D2+_3)
/HDMI switch B/B3_D2-: J13.3 (D2-), U5.13 (D2-_3)
/HDMI switch B/BO_CK+: J14.10 (CK+), U5.26 (CLK+_SINK)
/HDMI switch B/BO_CK-: J14.12 (CK-), U5.27 (CLK-_SINK)
/HDMI switch B/BO_D0+: J14.7 (D0+), U5.23 (D0+_SINK)
/HDMI switch B/BO_D0-: J14.9 (D0-), U5.24 (D0-_SINK)
/HDMI switch B/BO_D1+: J14.4 (D1+), U5.20 (D1+_SINK)
/HDMI switch B/BO_D1-: J14.6 (D1-), U5.21 (D1-_SINK)
/HDMI switch B/BO_D2+: J14.1 (D2+), U5.17 (D2+_SINK)
/HDMI switch B/BO_D2-: J14.3 (D2-), U5.18 (D2-_SINK)
CEC: J11.13 (CEC), J12.13 (CEC), J13.13 (CEC), J14.13 (CEC); also elsewhere on the board
GND: C14.2, C15.2, C16.2, C17.2, C18.2, C19.2, C20.2, C21.2, J11.2 (D2S), J11.5 (D1S), J11.8 (D0S), J11.11 (CKS), J11.17 (GND), J11.SH, J12.2 (D2S), J12.5 (D1S), J12.8 (D0S), J12.11 (CKS), J12.17 (GND), J12.SH, J13.2 (D2S), J13.5 (D1S), J13.8 (D0S), J13.11 (CKS), J13.17 (GND), J13.SH, J14.2 (D2S), J14.5 (D1S), J14.8 (D0S), J14.11 (CKS), J14.17 (GND), J14.SH, R3.2, R4.2, U5.3 (GND), U5.9 (GND), U5.15 (GND), U5.22 (GND), U5.28 (GND), U5.43 (GND), U5.58 (GND); also elsewhere on the board
HDMI_B_SCL: U5.32 (S1/SCL); also elsewhere on the board
HDMI_B_SDA: U5.33 (S2/SDA); also elsewhere on the board
unnamed: J11.15 (SCL), U5.37 (SCL1)
unnamed: J11.16 (SDA), U5.36 (SDA1)
unnamed: J11.19 (HPD), U5.35 (HPD1)
unnamed: J12.15 (SCL), U5.52 (SCL2)
unnamed: J12.16 (SDA), U5.51 (SDA2)
unnamed: J12.19 (HPD), U5.50 (HPD2)
unnamed: J13.15 (SCL), U5.2 (SCL3)
unnamed: J13.16 (SDA), U5.1 (SDA3)
unnamed: J13.19 (HPD), U5.64 (HPD3)
unnamed: J14.15 (SCL), R11.2, U5.29 (SCL_SINK)
unnamed: J14.16 (SDA), R12.2, U5.30 (SDA_SINK)
unnamed: J14.19 (HPD), U5.31 (HPD_SINK)
unnamed: R3.1, U5.34 (I2C_SEL)
unnamed: R4.1, U5.16 (VSadj)

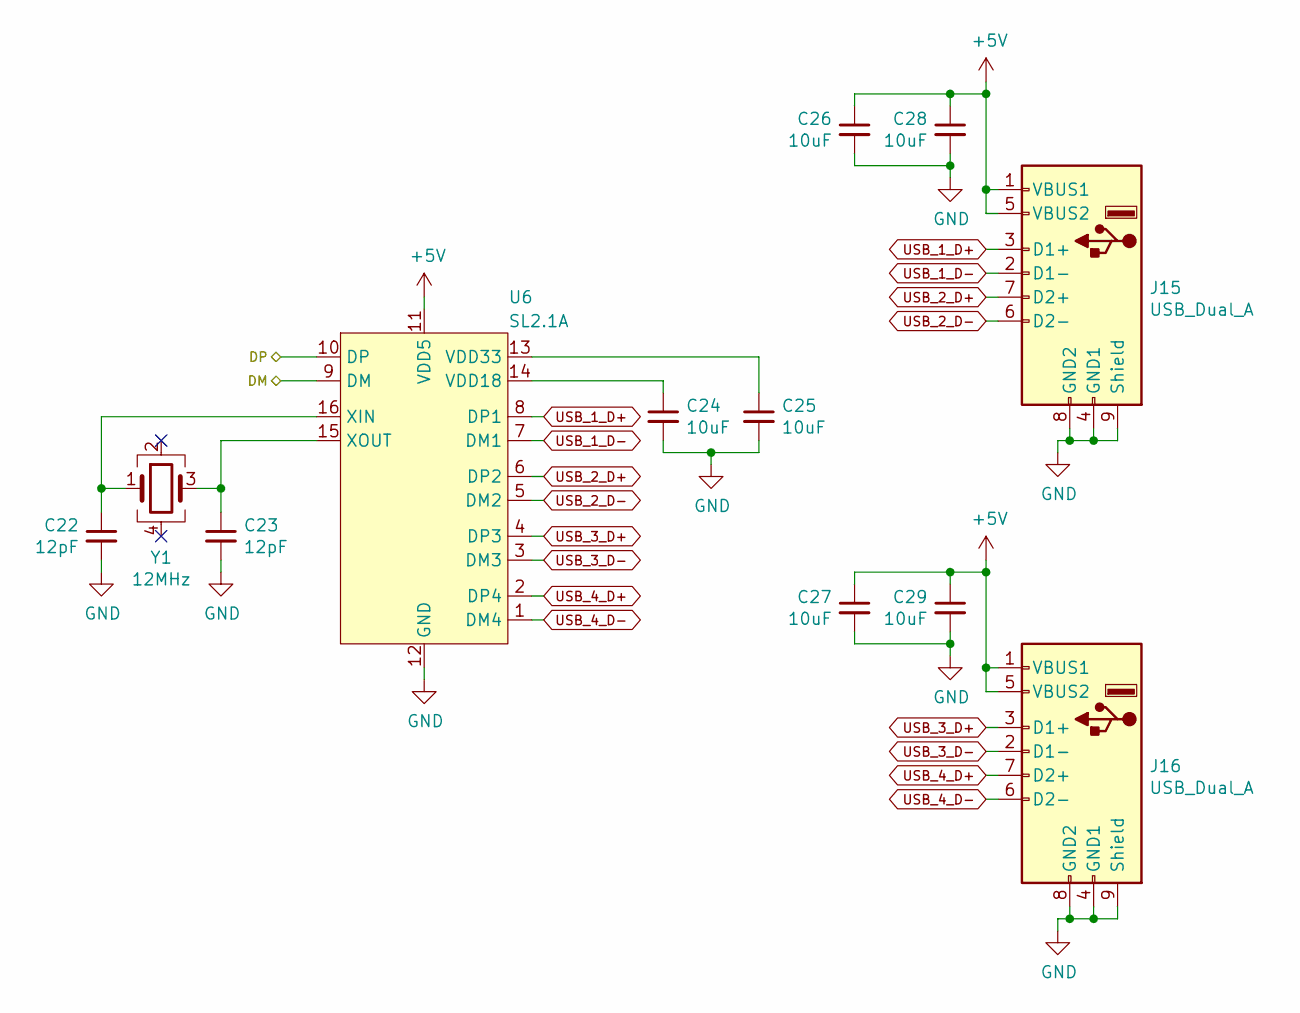
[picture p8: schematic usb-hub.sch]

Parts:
C22, C23: 12pF; C_0603_1608Metric_Pad1.05x0.95mm_HandSolder
C24, C25, C26, C27, C28, C29: 10uF; C_0603_1608Metric_Pad1.05x0.95mm_HandSolder
J15, J16: USB_Dual_A; USB_A_Wuerth_61400826021_Horizontal_Stacked
U6: SL2.1A; SOIC-16_3.9x9.9mm_P1.27mm
Y1: 12MHz; Crystal_SMD_3225-4Pin_3.2x2.5mm_HandSoldering

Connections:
+5V: C26.1, C27.1, C28.1, C29.1, J15.1 (VBUS1), J15.5 (VBUS2), J16.1 (VBUS1), J16.5 (VBUS2), U6.11 (VDD5); also elsewhere on the board
/USB_D+: U6.10 (DP); also elsewhere on the board
/USB_D-: U6.9 (DM); also elsewhere on the board
GND: C22.2, C23.2, C24.2, C25.2, C26.2, C27.2, C28.2, C29.2, J15.4 (GND1), J15.8 (GND2), J15.9 (Shield), J16.4 (GND1), J16.8 (GND2), J16.9 (Shield), U6.12 (GND); also elsewhere on the board
unnamed: C22.1, U6.16 (XIN), Y1.1
unnamed: C23.1, U6.15 (XOUT), Y1.3
unnamed: C24.1, U6.14 (VDD18)
unnamed: C25.1, U6.13 (VDD33)
USB_1_D+: J15.3 (D1+), U6.8 (DP1)
USB_1_D-: J15.2 (D1-), U6.7 (DM1)
USB_2_D+: J15.7 (D2+), U6.6 (DP2)
USB_2_D-: J15.6 (D2-), U6.5 (DM2)
USB_3_D+: J16.3 (D1+), U6.4 (DP3)
USB_3_D-: J16.2 (D1-), U6.3 (DM3)
USB_4_D+: J16.7 (D2+), U6.2 (DP4)
USB_4_D-: J16.6 (D2-), U6.1 (DM4)

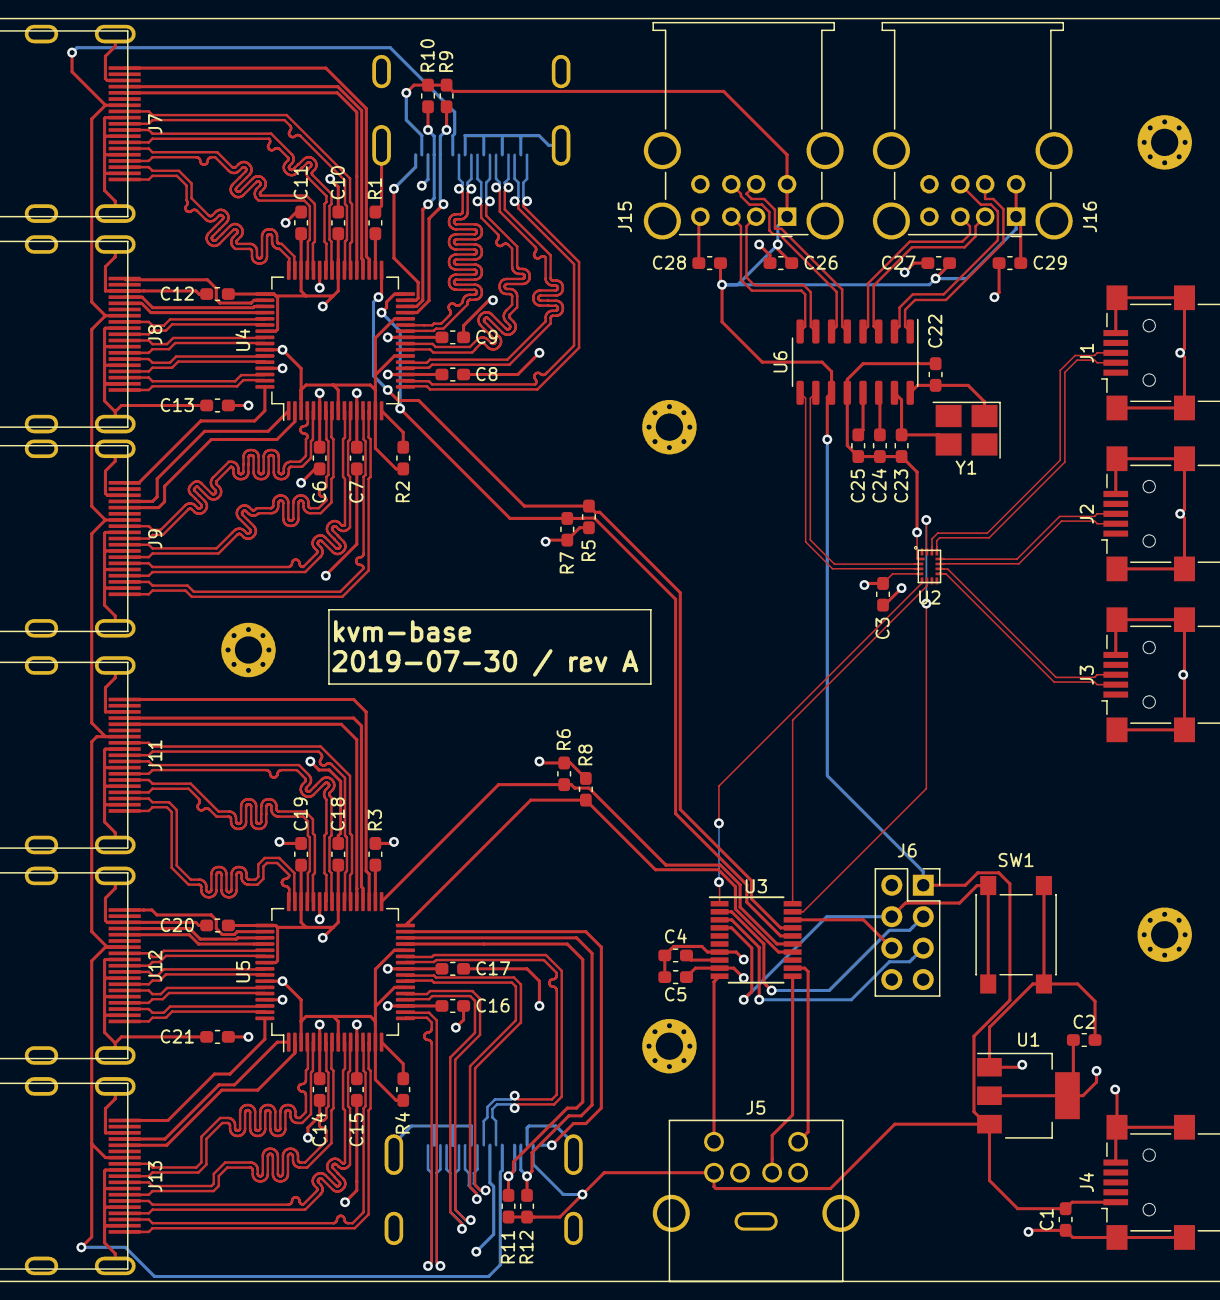
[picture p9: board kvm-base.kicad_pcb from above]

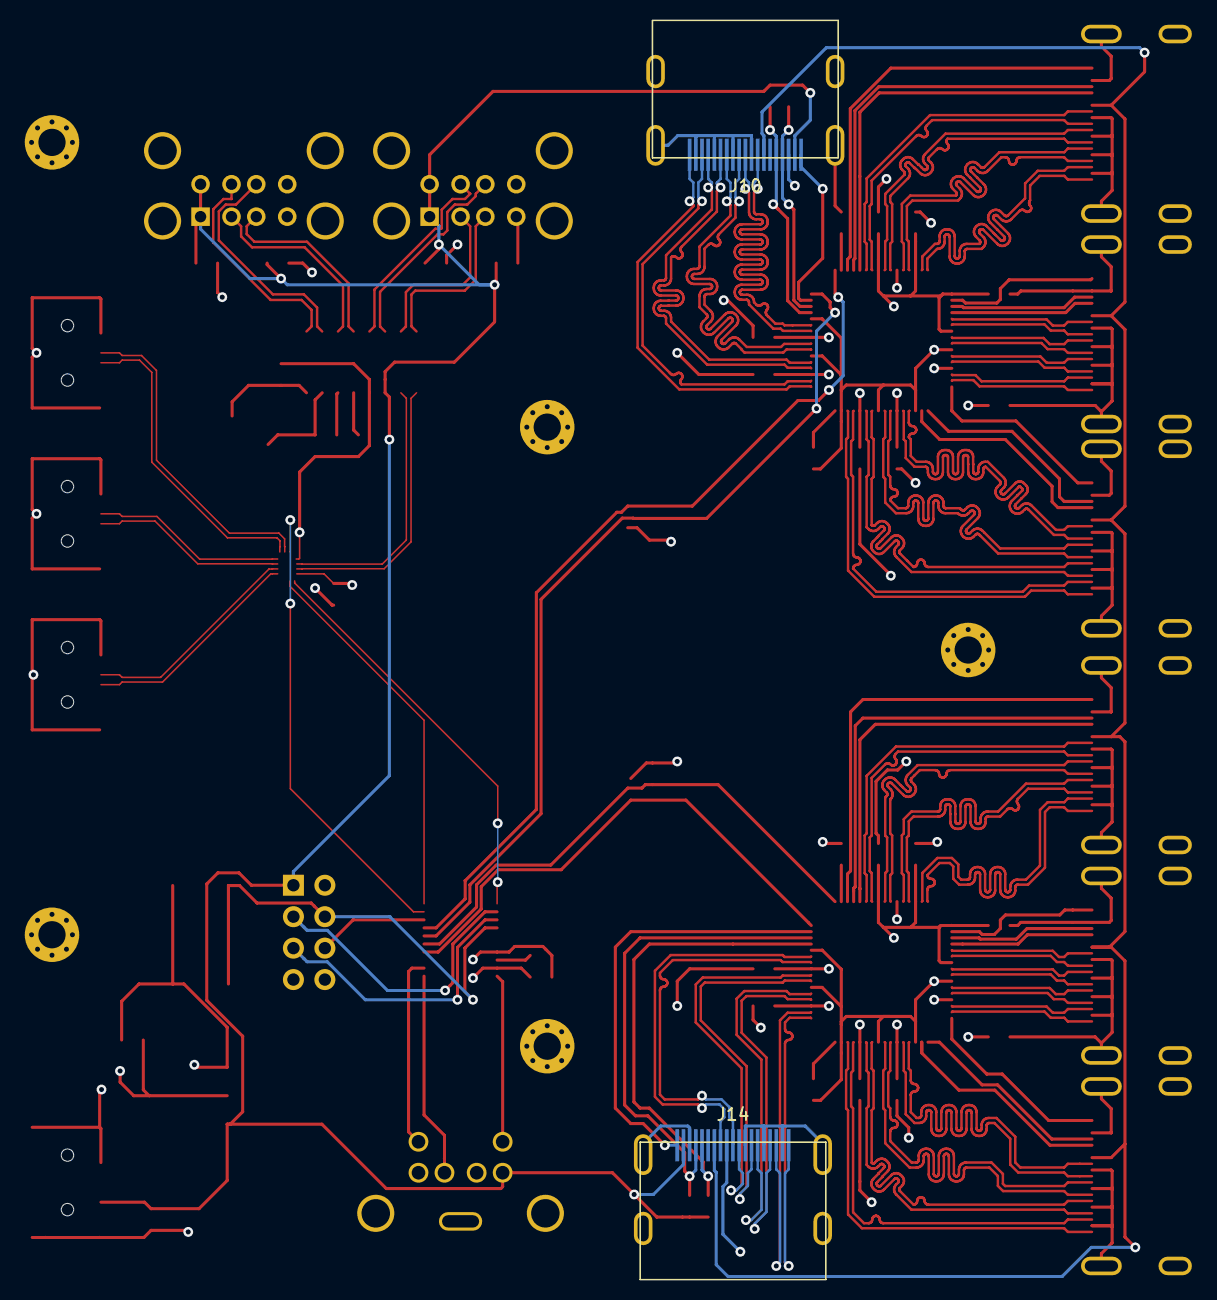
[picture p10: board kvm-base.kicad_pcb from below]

Board: 4 copper layers, 65 parts (2 on the bottom side), 131 nets.

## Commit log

2019-07-30 commit rev A schematic, pcb, and gerbers
    [hdmi-a.sch, hdmi-b.sch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]
2021-02-04 readme: add note about ps/2 cable
2021-02-04 add csv bom file for rev A
    [kvm-base.csv]
2021-02-04 readme: add links to schematic and bom
2021-02-12 readme: talk about output stage of tmds361b
2021-02-12 readme: move all the stuff about the tmds361b's output stage to a separate section
2021-02-12 readme: link to stackup and mention board thickness
2021-02-12 readme: add notes about assembly
2021-02-12 readme: add note on hdmi connector assembly
2021-02-12 readme: you also need some magnifier to assemble the hdmi connectors
2021-02-12 readme: add note about bom and pcb
2021-03-07 readme: mention tested cable length and monitor
2021-03-08 readme: add note about ESD diodes backfeeding power
2021-04-14 readme: use the proper term DDC instead of I2C
